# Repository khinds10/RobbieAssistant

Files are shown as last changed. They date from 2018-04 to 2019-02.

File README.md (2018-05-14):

# RobbieAssistant
Desktop Phone Notification Assistant Featuring (R.O.B.) Robotic Operating Buddy

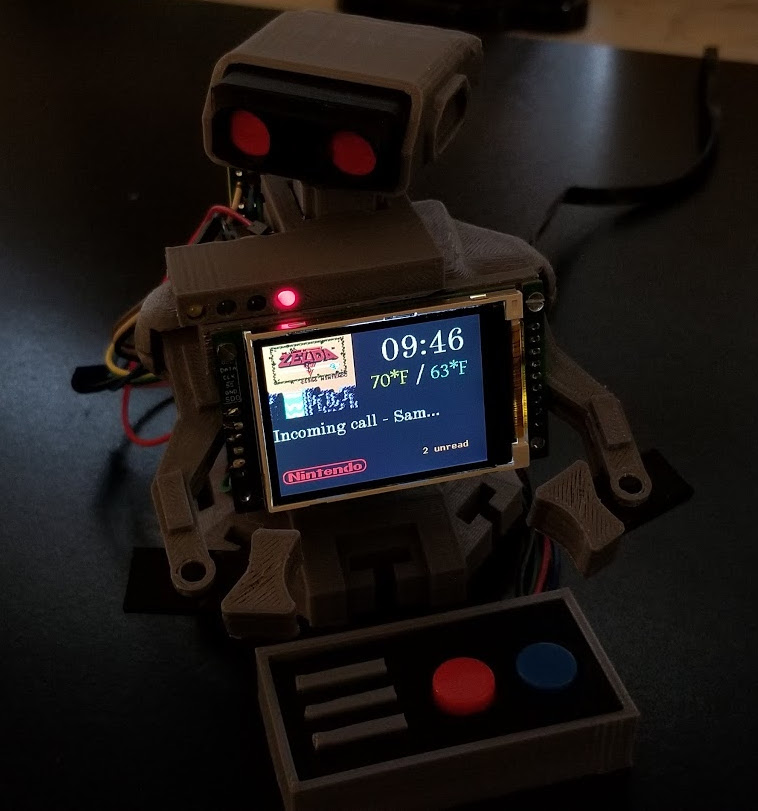
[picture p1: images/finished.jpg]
Finished!


Demo

#### Flashing RaspberriPi Hard Disk / Install Required Software (Using Ubuntu Linux)

Download "RASPBIAN JESSIE LITE"
https://www.raspberrypi.org/downloads/raspbian/

**Create your new hard disk for DashboardPI**
>Insert the microSD to your computer via USB adapter and create the disk image using the `dd` command
>
> Locate your inserted microSD card via the `df -h` command, unmount it and create the disk image with the disk copy `dd` command
> 
> $ `df -h`
> */dev/sdb1       7.4G   32K  7.4G   1% /media/XXX/1234-5678*
> 
> $ `umount /dev/sdb1`
> 
> **Caution: be sure the command is completely accurate, you can damage other disks with this command**
> 
> *if=location of RASPBIAN JESSIE LITE image file*
> *of=location of your microSD card*
> 
> $ `sudo dd bs=4M if=/path/to/raspbian-jessie-lite.img of=/dev/sdb`
> *(note: in this case, it's /dev/sdb, /dev/sdb1 was an existing factory partition on the microSD)*

**Setting up your RaspberriPi**

*Insert your new microSD card to the raspberrypi and power it on with a monitor connected to the HDMI port*

Login
> user: **pi**
> pass: **raspberry**

Change your account password for security
>`sudo passwd pi`

Enable RaspberriPi Advanced Options
>`sudo raspi-config`

Choose:
`1 Expand File System`

`9 Advanced Options`
>`A2 Hostname`
>*change it to "RobbieAssistant"*
>
>`A4 SSH`
>*Enable SSH Server*
>
>`A7 I2C`
>*Enable i2c interface*

**Enable the English/US Keyboard**

>`sudo nano /etc/default/keyboard`

> Change the following line:
>`XKBLAYOUT="us"`

**Reboot PI for Keyboard layout changes / file system resizing to take effect**
>$ `sudo shutdown -r now`

**Auto-Connect to your WiFi**

>`sudo nano /etc/wpa_supplicant/wpa_supplicant.conf`

Add the following lines to have your raspberrypi automatically connect to your home WiFi
*(if your wireless network is named "linksys" for example, in the following example)*

	network={
	   ssid="linksys"
	   psk="WIRELESS PASSWORD HERE"
	}

**Reboot PI to connect to WiFi network**

>$ `sudo shutdown -r now`
>
>Now that your PI is finally on the local network, you can login remotely to it via SSH.
>But first you need to get the IP address it currently has.
>
>$ `ifconfig`
>*Look for "inet addr: 192.168.XXX.XXX" in the following command's output for your PI's IP Address*

**Go to another machine and login to your raspberrypi via ssh**

> $ `ssh pi@192.168.XXX.XXX`

**Start Installing required packages**

>$ `sudo apt-get update`
>
>$ `sudo apt-get upgrade`
>
>$ `sudo apt-get install build-essential tk-dev libbz2-dev libexpat1-dev liblzma-dev zlib1g-dev libdb5.3-dev libgdbm-dev libsqlite3-dev libssl-dev libncurses5-dev libncursesw5-dev libreadline6-dev python3-pip python3-requests python3-setuptools python3-urllib python3-urllib3 python3-requests vim git python-smbus i2c-tools python-imaging python-smbus build-essential python-dev rpi.gpio python3 python3-pip vim git python-smbus i2c-tools python-imaging python-smbus build-essential python-dev rpi.gpio python3 python3-pip libi2c-dev vim git python-smbus i2c-tools python-imaging python-smbus build-essential python-dev rpi.gpio python3 python3-pip python-gpiozero python-psutil xz-utils`
>
>$ `sudo pip install requests`

**Update local timezone settings

>$ `sudo dpkg-reconfigure tzdata`

`select your timezone using the interface`

**Setup the simple directory `l` command [optional]**

>`vi ~/.bashrc`
>
>*add the following line:*
>
>`alias l='ls -lh'`
>
>`source ~/.bashrc`

**Fix VIM default syntax highlighting [optional]**

>`sudo vi  /etc/vim/vimrc`
>
>uncomment the following line:
>
>_syntax on_

**make the logs folder for the application to run**

`mkdir /home/pi/RobbieAssistant/logs`

`chmod 777 /home/pi/RobbieAssistant/logs`

**Configure Application to run correctly in settings.py config file**

Find the file `settings-shadow.py` in the `/includes/` folder of the project and copy it to `settings.py` and adjust to your current settings

> \# forecast.io API key for local weather information
>
> weatherAPIURL = 'https://api.forecast.io/forecast/'
>
> weatherAPIKey = 'YOUR API KEY FOR FORECAST.IO'
> 
> \# optional for running the remote temp/humidity logger
>
> dashboardServer = 'mydevicelogger.com'
>
> \# search google to get the Latitude/Longitude for your home location
>
> latitude = 41.4552578
>
> longitude = -72.1665444
>

# Supplies Needed

**RaspberriPi Zero**

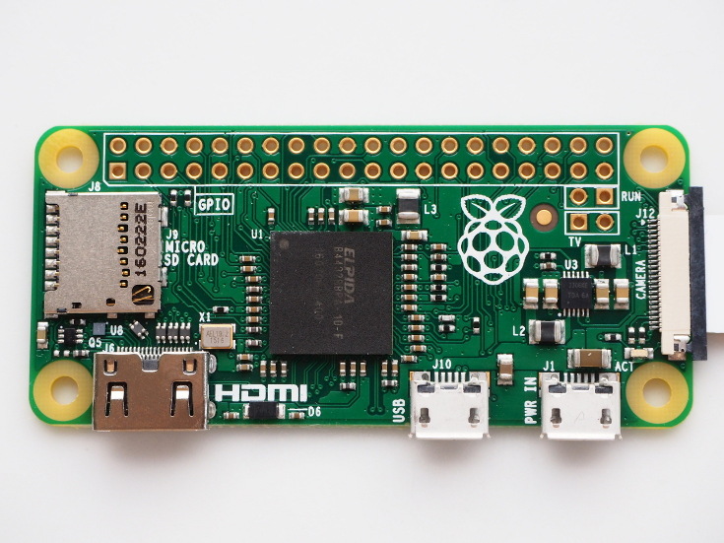
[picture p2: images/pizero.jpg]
Pi Zero


**DHT11 Humidistat**

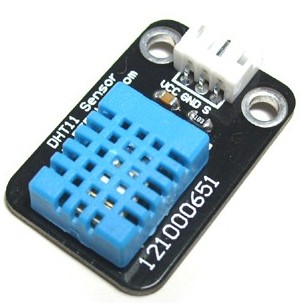
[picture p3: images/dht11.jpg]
DHT11 Humidistat


LED Lights (x4) Green / Yellow / Blue / Red

LED Lights

**2.6" Digole Display**

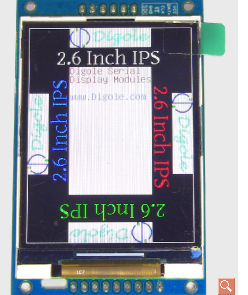
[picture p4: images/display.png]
Digole Display


## Build and wire the device

**1) Prepare the Digole Display for i2C**

On the back of the Digole Display, solder the jumper to assign the display to use the i2c protocol
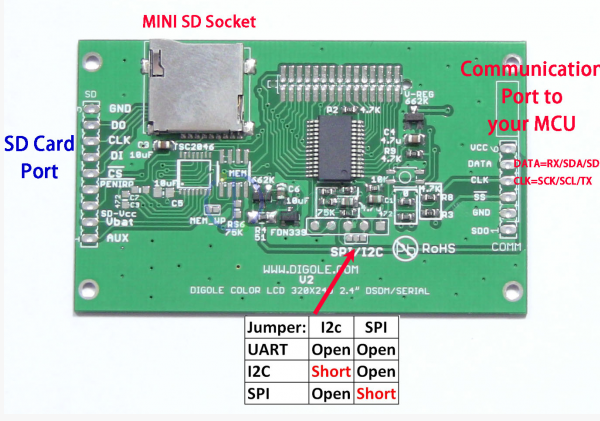
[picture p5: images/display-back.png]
i2c Jumper Digole


## Using a 3d printer, print the cover, box and back panels

Using the following X STL files in the `3DPrint` folder, R.O.B. Robot, LED Harness and Display Mount
>
> buttonContainer-base.stl
>
> buttonContainer-lid.stl
>
> displaymount-final.stl
>
> led-harness-final.stl
>
> MiniNintendoROB.zip

Robot Print by: Mini Nintendo R.O.B. - by RabbitEngineering

https://www.thingiverse.com/thing:1494964

I used red tape to make the eyes red with the black visor background

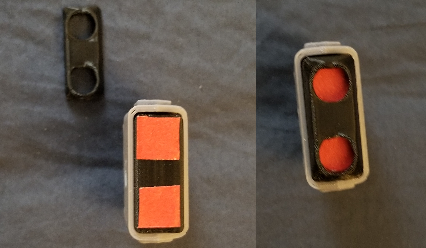
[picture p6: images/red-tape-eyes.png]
Red Tape


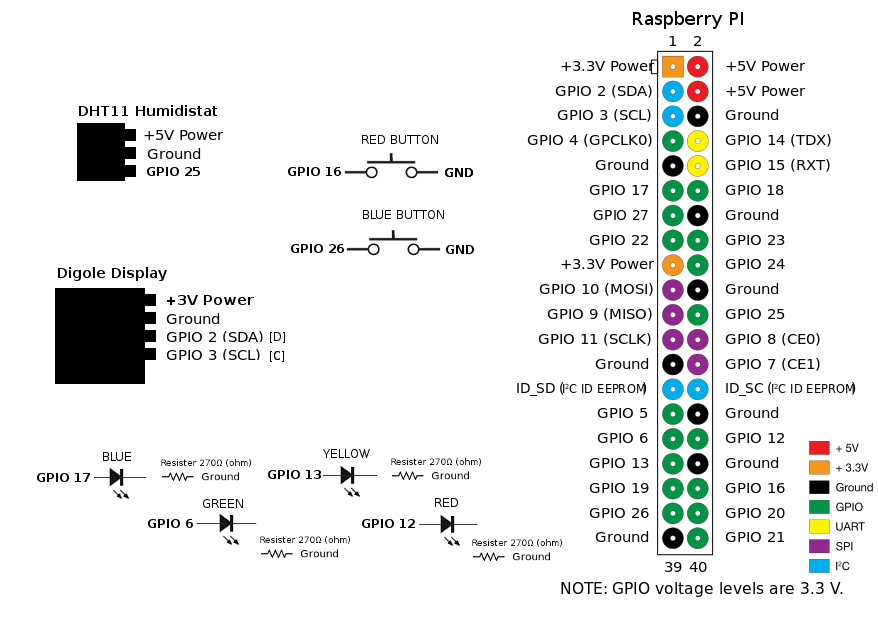
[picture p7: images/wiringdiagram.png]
Wiring Diagram


**Digole Display**
>
> GND -> GND
>
> DATA -> SDA
>
> CLK -> SCL
>
> VCC -> 3V
    
**DHT11 Humidistat**
>
> VCC -> 5V
>
> GND -> GND
>
> DATA -> GPIO 25
>

**BLUE Resistor**
>
> VCC -> GPIO 17 (with 270ohm resistor)
>
> GND -> GND
>

**YELLOW Resistor**
>
> VCC -> GPIO 13 (with 270ohm resistor)
>
> GND -> GND
>

**GREEN Resistor**
>
> VCC -> GPIO 6 (with 270ohm resistor)
>
> GND -> GND
>

**RED Resistor**
>
> VCC -> GPIO 12 (with 270ohm resistor)
>
> GND -> GND
>

**RED Momentary Pushbutton**
>
> VCC -> GPIO 16 (with 270ohm resistor)
>
> GND -> GND
>

**BLUE Momentary Pushbutton**
>
> VCC -> GPIO 26 (with 270ohm resistor)
>
> GND -> GND
>

After you've printed the screen holder, connect it to the digole display

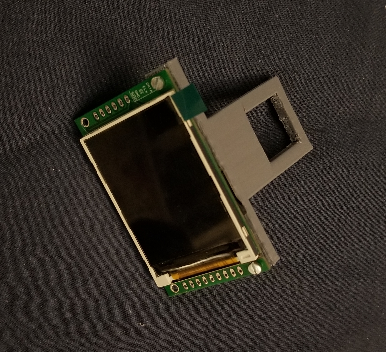
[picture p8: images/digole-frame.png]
Digole w/ Frame


Connect the Display to the RPi with enough wiring to glue the RPi to the back of the robot

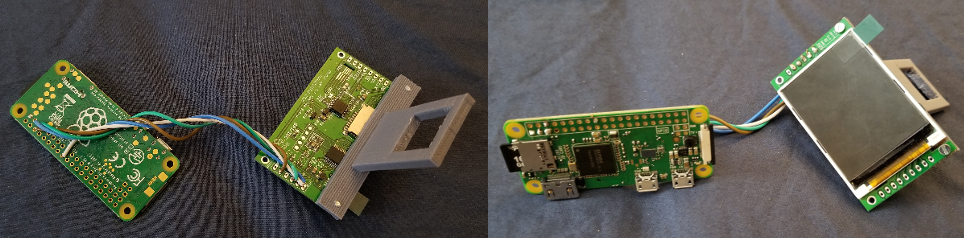
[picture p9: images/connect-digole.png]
Connect Digole


Print the controller and wire the buttons with enough wiring to make it to the back of the robot

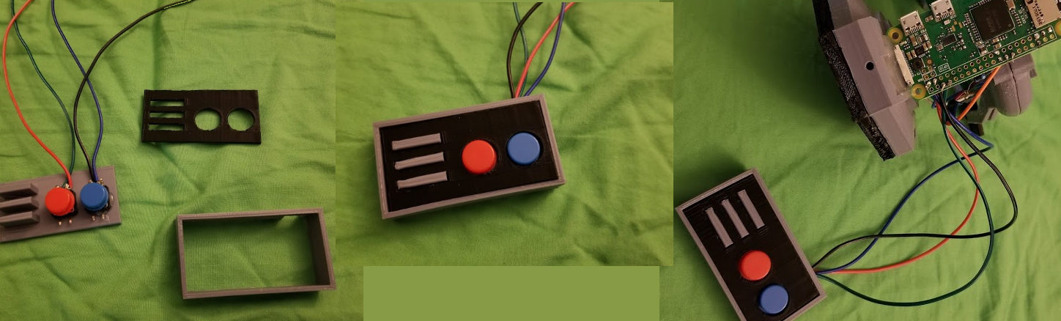
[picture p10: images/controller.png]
Controller


Finish Wiring and assembling the robot with the RPi connected to the back and the DHT11 glued to the bottom

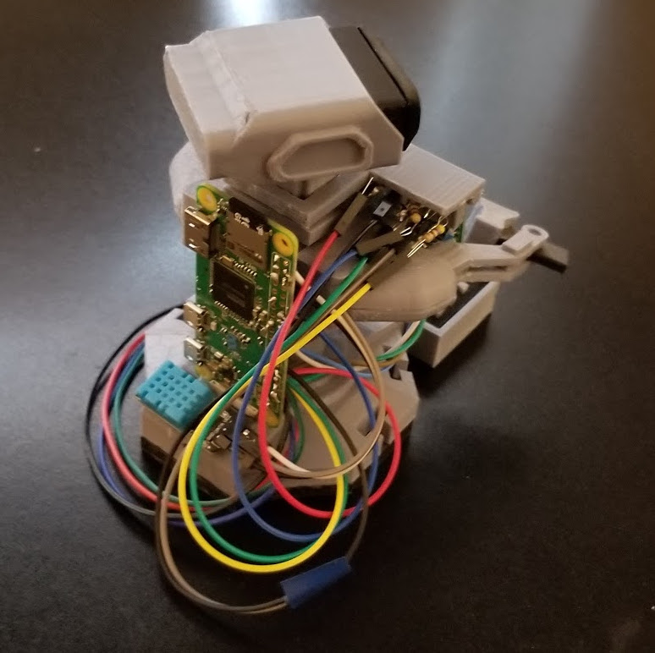
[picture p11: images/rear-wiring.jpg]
Rear Wiring


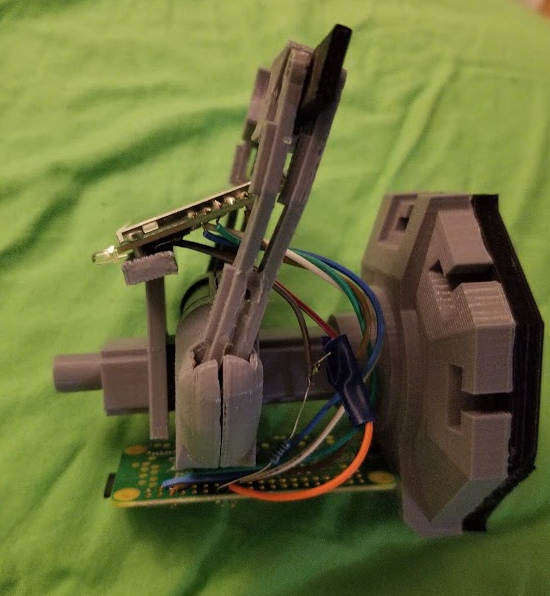
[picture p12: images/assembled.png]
Assembled


## Check I2C Configuration

Start up your RaspberryPi and make sure the I2C bus recognizes all your connected 7/14 segment displays. 
*[each display is given a unique address described above by how you solder each display's jumpers in different combinations]*

If you have the display with jumper soldered correctly, you should have the following output for the `i2cdetect` command:

`sudo i2cdetect -y 1`
     
>     0  1  2  3  4  5  6  7  8  9  a  b  c  d  e  f
>
>00:          -- -- -- -- -- -- -- -- -- -- -- -- -- 
>
>10: -- -- -- -- -- -- -- -- -- -- -- -- -- -- -- -- 
>
>20: -- -- -- -- -- -- -- 27 -- -- -- -- -- -- -- -- 
>
>30: -- -- -- -- -- -- -- -- -- -- -- -- -- -- -- -- 
>
>40: -- -- -- -- -- -- -- -- -- -- -- -- -- -- -- -- 
>
>50: -- -- -- -- -- -- -- -- -- -- -- -- -- -- -- -- 
>
>60: -- -- -- -- -- -- -- -- -- -- -- -- -- -- -- -- 
>
>70: -- -- -- -- -- -- -- --
>

**DHT11 Install**

>$ `cd ~`
>
>$ `git clone https://github.com/adafruit/Adafruit_Python_DHT.git`
>
>$ `cd Adafruit_Python_DHT/`
>
>$ `sudo python setup.py install`
>
>$ `sudo python ez_setup.py`
>
>$ `cd examples/`
>
>$ `vi simpletest.py`
>

Change the following line:
> sensor = Adafruit_DHT.DHT11

Comment the line out
> pin = 'P8_11'

Uncomment the line and change the pin number to 16
> pin = 25

Run the test

`python simpletest.py`

> You should see a metric reading of Temp and Humidity displayed on the command line.

**Clone RobbieAssistant repository**

>$ `cd ~`
>
>$ `git clone https://github.com/khinds10/RobbieAssistant.git`

**PushBullet/**

*Using the pushbullet app for your phone, signup to recieve an API key to have a simple python script be able to capture and push data hub notifications and indicator flags*

Install Python 3.5 for asyncio functionality

	sudo apt-get update
	sudo apt-get install build-essential tk-dev
	sudo apt-get install libncurses5-dev libncursesw5-dev libreadline6-dev
	sudo apt-get install libdb5.3-dev libgdbm-dev libsqlite3-dev libssl-dev
	sudo apt-get install libbz2-dev libexpat1-dev liblzma-dev zlib1g-dev

If one of the packages cannot be found, try a newer version number (e.g. libdb5.4-dev instead of libdb5.3-dev).

	wget https://www.python.org/ftp/python/3.5.2/Python-3.5.2.tgz
	tar zxvf Python-3.5.2.tgz
	cd Python-3.5.2
	./configure --prefix=/usr/local/opt/python-3.5.2
	make
	sudo make install
	sudo ln -s /usr/local/opt/python-3.5.2/bin/pydoc3.5 /usr/bin/pydoc3.5
	sudo ln -s /usr/local/opt/python-3.5.2/bin/python3.5 /usr/bin/python3.5
	sudo ln -s /usr/local/opt/python-3.5.2/bin/python3.5m /usr/bin/python3.5m
	sudo ln -s /usr/local/opt/python-3.5.2/bin/pyvenv-3.5 /usr/bin/pyvenv-3.5
	sudo ln -s /usr/local/opt/python-3.5.2/bin/pip3.5 /usr/bin/pip3.5
	cd ~
	echo 'alias python35="/usr/local/opt/python-3.5.2/bin/python3.5"' >> .bashrc
	echo 'alias idle35="/usr/local/opt/python-3.5.2/bin/python3.5"' >> .bashrc

Install the python3 dependancies

	sudo apt-get install python3-setuptools
	sudo apt-get install python3-pip
	sudo pip3 install asyncpushbullet
    sudo pip3 install requests
    
*Optional way* Download the python repository directly to obtain the python dependancies without the use of pip installing it

    git clone https://github.com/rharder/asyncpushbullet
    cd asyncpushbullet && sudo /usr/local/opt/python-3.5.2/bin/python3.5 setup.py install

Visit the pushbullet settings page in your account to generate an API key to use
https://www.pushbullet.com/#settings

Configure your `pushbullet-listener.py` script to have the correct API and dashboard central host

	# your API Key from PushBullet.com
	API_KEY = "o.XXXYYYZZZ111222333444555666"

	# dashboard central server host
	dashboardServer = 'MY-SERVER-HERE.com'

Add the script to start at dashboard boot and restart your dashboard pi

$ `crontab -e`

`@reboot nohup /usr/local/opt/python-3.5.2/bin/python3.5 /home/pi/PushBullet/pushbullet-listener.py >/dev/null 2>&1`

`@reboot nohup /usr/local/opt/python-3.5.3/bin/python3.5 /home/pi/RobbieAssistant/PushBullet/pushbullet-listener.py > /dev/null 2>&1`

`@reboot nohup python /home/pi/RobbieAssistant/Robbie.py > /dev/null 2>&1`

`@reboot nohup python /home/pi/RobbieAssistant/Temp.py > /dev/null 2>&1`

`@reboot nohup python /home/pi/RobbieAssistant/Weather.py > /dev/null 2>&1`

## OPTIONAL: Creating your own Nintendo images to render on the display

Upload your own 128x128 file to the following URL:

http://www.digole.com/tools/PicturetoC_Hex_converter.php 

Choose your image file to upload, add what size you want it to be on the screen (Width/Height)

Select "256 Color for Color OLED/LCD(1 byte/pixel)" in the "Used for" dropdown

Obtain the hex output.

Add the hex output to a display/build/ header (.h) file, use the other ones as guides for syntax.

Include the new file in the digole.c file 
`#include "myimage.h`

Include a new command line hook to your image file in the.
_Note: the command below is saying draw your image at position 10 pixels over 10  pixels down. You can change it to different X,Y coordinates, you can also change the values 128,128 to whatever size your new image actually is._

`} else if (strcmp(digoleCommand, "myimage") == 0) {`
    `drawBitmap256(10, 10, 128, 128, &myimageVariableHere,0);  // myimageVariableHere is defined in your (.h) file`
`}`

Now rebuild (ignore the errors) below to have your new image render with the following command.
>$ `./digole myimage`

**Re-Building [Included] Digole Display Driver for your optional changes**

>$ `cd display/build`

>$ `gcc digole.c`

>$ `mv a.out ../../digole`

>$ `chmod +x ../../digole`

## Finished

Finished!

Demo

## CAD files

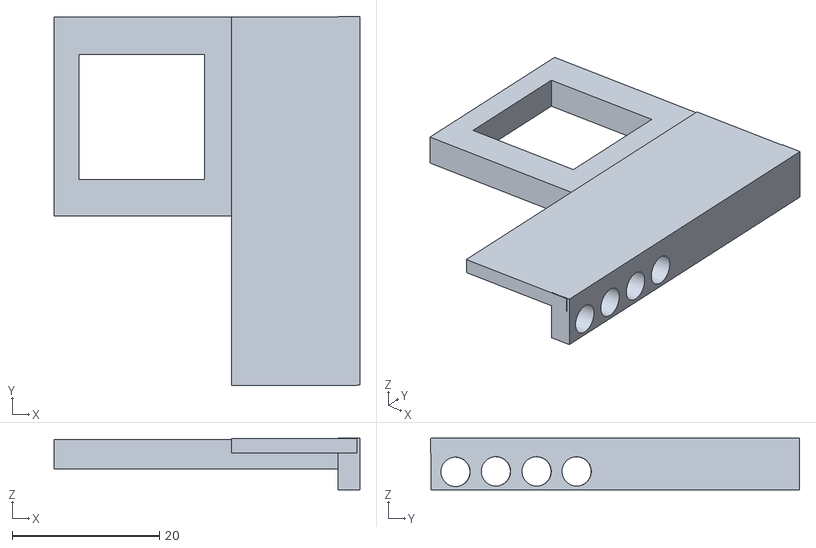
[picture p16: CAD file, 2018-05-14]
3DPrint/led-harness-final.stl
41.5 x 50.1 x 7.00

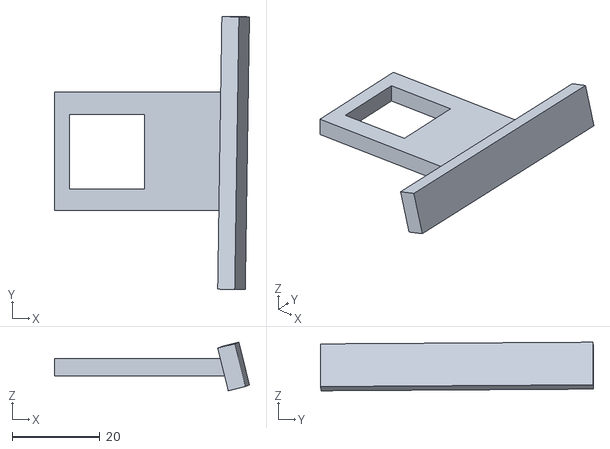
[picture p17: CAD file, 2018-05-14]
3DPrint/displaymount-final.stl
44.3 x 62.1 x 11.1

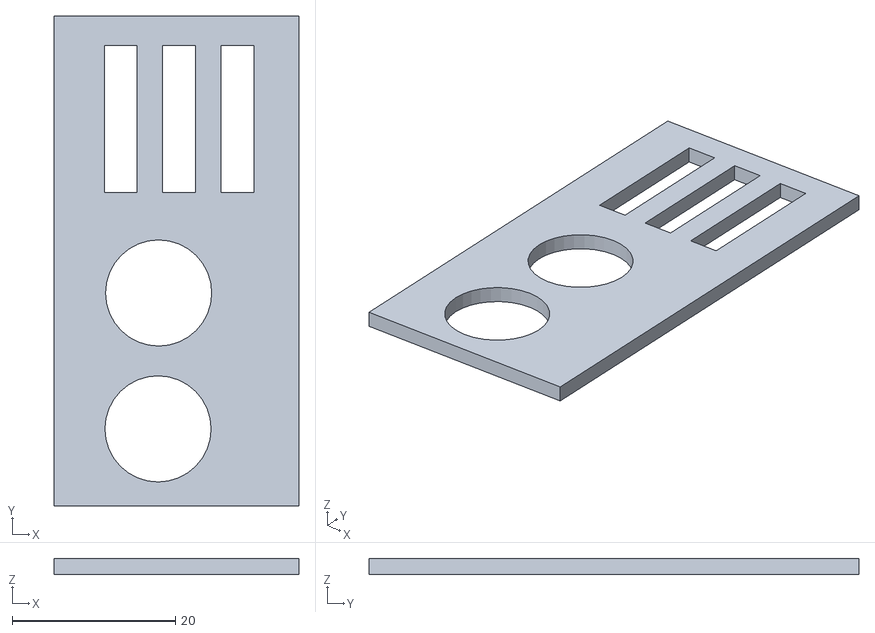
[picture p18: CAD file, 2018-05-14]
3DPrint/buttonContainer-lid.stl
30.0 x 60.0 x 2.00

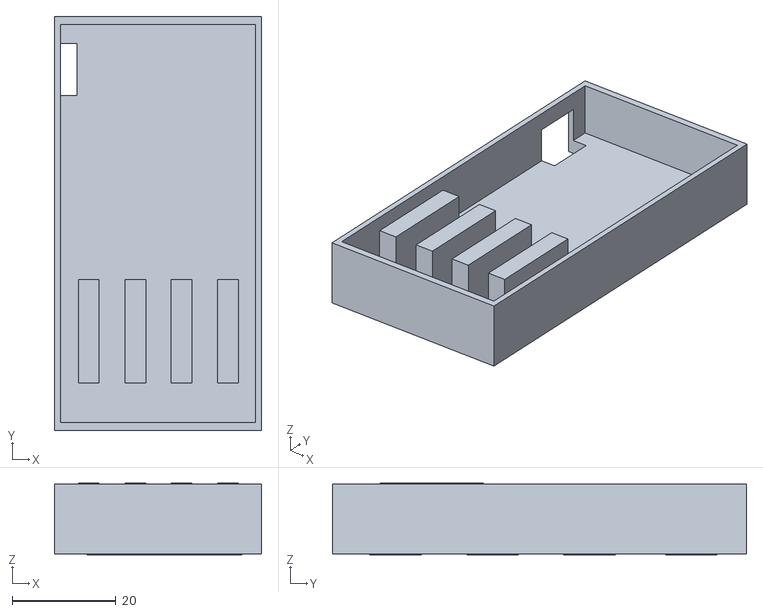
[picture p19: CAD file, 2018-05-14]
3DPrint/buttonContainer-base.stl
40.0 x 80.0 x 13.9

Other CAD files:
3DPrint/buttonContainer-base.blend
3DPrint/buttonContainer-lid.blend
3DPrint/displaymount-final.blend
3DPrint/led-harness-final.blend

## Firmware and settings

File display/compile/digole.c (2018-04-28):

/////////////////////////////////
// Digole Digital
/////////////////////////////////
#include <arpa/inet.h>
#include <dirent.h>
#include <errno.h>
#include <net/if.h>
#include <netinet/in.h>
#include <netinet/in.h>
#include <pthread.h>
#include <stdint.h>
#include <stdio.h>
#include <stdlib.h>
#include <string.h>
#include <stropts.h>
#include <sys/ioctl.h>
#include <sys/socket.h>
#include <sys/types.h>
#include <sys/time.h>
#include <time.h>
#include <unistd.h>
#include <inttypes.h>
#include <linux/i2c-dev.h>
#include <fcntl.h>
#include <sys/ioctl.h>
#include <sys/stat.h>

// include all the NES Title Screen Images
#include "BlasterMaster.h"
#include "Castlevania.h"
#include "ChipDale.h"
#include "Contra.h"
#include "ClearTitle.h"
#include "DuckTales.h"
#include "Galaga.h"
#include "GhostBusters.h"
#include "Gradius.h"
#include "KidIcarus.h"
#include "MarbleMadness.h"
#include "MegaMan.h"
#include "MetalGear.h"
#include "Metroid.h"
#include "PunchOut.h"
#include "SuperMario2.h"
#include "SuperMario3.h"
#include "TMNT2.h"
#include "TopGun.h"
#include "Turtles.h"
#include "Zelda.h"
#include "NES.h"

#define _TEXT_ 0
#define _GRAPH_ 1
#define _rs 0
#define _rst 2
#define LCDWIDTH 128
#define LCDHEIGHT 64

// an abs() :)
#define abs(a) (((a) < 0) ? -(a) : (a))

// bit set
#define _BV(bit) (0x1 << (bit))
#define swap(a, b) { uint8_t t = a; a = b; b = t; }

int fd,fd2;
const unsigned char fonts[] = {6, 10, 18, 51, 120, 123};

// name of the port we will be using, Rasberry Pi model B (i2c-1)
char *fileName = "/dev/i2c-1";

// address of I2C device Digole
int  address = 0x27;

void delay (unsigned int howLong){
  struct timespec sleeper, dummy ;
  sleeper.tv_sec  = (time_t)(howLong / 1000) ;
  sleeper.tv_nsec = (long)(howLong % 1000) * 1000000 ;
  nanosleep (&sleeper, &dummy) ;
}
 int writebyte (uint8_t command) {
	    if( i2c_smbus_write_byte( fd, command ) < 0 ) {
            printf(" Error writing to i2c slave ");
			return -1;
        }
		return 0;
 }
 int writecmd(char *command) {
		char tmp[1000];
		int i;
		sprintf(tmp,"%s",command);
        printf(" Digole CMD: %s ",command);
		for (i=0;i<strlen(tmp);i++) {
			printf("%c",tmp[i]);
		    if ((writebyte(tmp[i]))==-1) {
				printf(" Error writing to i2c slave ");
				return -1;
			}
		}
		return 0;
 }
void setRot90(void) {
    writecmd("SD1");
}
void setRot180(void) {
    writecmd("SD2");
}
void setRot270(void) {
    writecmd("SD3");
}
void undoRotation(void) {
    writecmd("SD0");
}
void setRotation(uint8_t d) {
    writecmd("SD");
    writebyte(d);
}
void setContrast(uint8_t c) {
    writecmd("CT");
    writebyte(c);
}
int print(char *command) {
    char tmp[1000];
    writecmd("TT");
    writecmd(command);
    writebyte(0);
    return 0;
}
void displayStartScreen(uint8_t c) {
    writecmd("DSS");
    writebyte(c);
}
void drawBox(uint8_t x, uint8_t y, uint8_t w, uint8_t h) {
    writecmd("FR");
    writebyte(x);
    writebyte(y);
    writebyte(x + w);
    writebyte(y + h);
}
void drawFrame(uint8_t x, uint8_t y, uint8_t w, uint8_t h) {
    writecmd("DR");
    writebyte(x);
    writebyte(y);
    writebyte(x + w);
    writebyte(y + h);
}
void setColor(uint8_t color) {
    writecmd("SC");
    writebyte(color);
}
void drawBoxfill(uint8_t x, uint8_t y, uint8_t w, uint8_t h) {
	setColor(0);
	drawBox(x, y, w,h);
	setColor(1);
	drawFrame(x, y, w,h);
}
void clearobd() {
	setColor(0);
	drawBox(0, 0, 128,57);
	setColor(1);
}
void drawCircle(uint8_t x, uint8_t y, uint8_t r, uint8_t f) {
    writecmd("CC");
    writebyte(x);
    writebyte(y);
    writebyte(r);
    writebyte(f);
}
void drawDisc(uint8_t x, uint8_t y, uint8_t r) {
    drawCircle(x, y, r, 1);
}
void drawPixel(uint8_t x, uint8_t y, uint8_t color) {
    writecmd("DP");
    writebyte(x);
    writebyte(y);
    writebyte(color);
}
void drawLine(uint8_t x, uint8_t y, uint8_t x1, uint8_t y1) {
    writecmd("LN");
    writebyte(x);
    writebyte(y);
    writebyte(x1);
    writebyte(y1);
}
void drawLineTo(uint8_t x, uint8_t y) {
    writecmd("LT");
    writebyte(x);
    writebyte(y);
}
void drawHLine(uint8_t x, uint8_t y, uint8_t w) {
    drawLine(x, y, x + w, y);
}
void drawVLine(uint8_t x, uint8_t y, uint8_t h) {
    drawLine(x, y, x, y + h);
}
void nextTextLine(void) {
    writebyte((uint8_t) 0);
    writecmd("TRT");
}
void setFont(uint8_t font) {
    writecmd("SF");
    writebyte(font);
}
void directCommand(uint8_t d) {
    writecmd("MCD");
    writebyte(d);
}
void directData(uint8_t d) {
    writecmd("MDT");
    writebyte(d);
}
void moveArea(uint8_t x0, uint8_t y0, uint8_t x1, uint8_t y1, char xoffset, char yoffset) {
    writecmd("MA");
    writebyte(x0);
    writebyte(y0);
    writebyte(x1);
    writebyte(y1);
    writebyte(xoffset);
    writebyte(yoffset);
}
void uploadStartScreen(int lon,  uint8_t *data,int xdelay) {
     int j,y;
     uint8_t c;
    writecmd("SSS");
    writebyte((uint8_t) (lon % 256));
    writebyte((uint8_t) (lon / 256));
    for (j = 0; j < lon;j++) {
        delay(xdelay);
        c=*(data+j);
        writebyte(c);
		printf(" 0x%.2X ",c);
		if ((j%16)==0) printf(" ");
    }
}
void uploadUserFont(int lon, uint8_t *data, uint8_t sect) {
     uint8_t c;
	 int j;
    writecmd("SUF");
    writebyte(sect);
    writebyte((uint8_t) (lon % 256));
    writebyte((uint8_t) (lon / 256));
    for ( j = 0; j < lon; j++) {
        if((j%32)==0) delay(10);
        delay(2);
        c=*(data+j);
        writebyte(c);
    }
}
void clearScreen(void) {
        writebyte('C');
		writebyte('L');
		writebyte(0);
		writebyte('C');
		writebyte('L');
		writebyte(0);
}
//set display mode
void setMode(uint8_t m) {
        writecmd("DM");
        writebyte(m);
}
//set text position back to previous, only one back allowed
void setTextPosBack(void) {
	writecmd("ETB");
}
void setTextPosOffset(char xoffset, char yoffset) {
	writecmd("ETO");
	writebyte(xoffset);
	writebyte(yoffset);
}
void setTextPosAbs(uint8_t x, uint8_t y) {
	writecmd("ETP");
	writebyte(x);
	writebyte(y);
}
void setLinePattern(uint8_t pattern) {
	writecmd("SLP");
	writebyte(pattern);
 }
void setPrintPos(uint8_t x, uint8_t y, uint8_t graph ) {
        if (graph == _TEXT_)
            writecmd("TP");
		else
            writecmd("GP");
         writebyte(x);
         writebyte(y);
}
void disableCursor(void) {
    writecmd("CS0");
}
void enableCursor(void) {
    writecmd("CS1");
}
void drawStr(uint8_t x, uint8_t y, char *s) {
		setTextPosOffset(x,y);
		print(s);
}
/*----------Functions for Graphic LCD/OLED adapters only---------*/
void drawBitmap(uint8_t x, uint8_t y, uint8_t w, uint8_t h, const uint8_t *bitmap) {
    uint8_t i = 0;
	int j;
    if ((w & 7) != 0)
        i = 1;
    writecmd("DIM");
    writebyte(x); //x;
    writebyte(y);
    writebyte(w);
    writebyte(h);
    for ( j = 0; j < h * ((w >> 3) + i); j++) {
        writebyte(*(bitmap + j));
    }
}
void drawBitmap256(uint8_t x, uint8_t y, uint8_t w, uint8_t h, unsigned char *bitmap,uint8_t c ) {
	int j;
    writecmd("EDIM1");
    writebyte(x);
    writebyte(y);
    writebyte(w);
    writebyte(h);    
    for ( j = 0; j < h * w; j++) {
        writebyte(*(bitmap + j));
    }
}
void drawBitmapc(uint8_t x, uint8_t y, uint8_t w, uint8_t h, unsigned char *bitmap,uint8_t c ) {
    uint8_t i = 0;
	int j;
	if (c!=0) c=0xff;
    if ((w & 7) != 0)
        i = 1;
    writecmd("EDIM1");
    writebyte(x);
    writebyte(y);
    writebyte(w);
    writebyte(h);
    for ( j = 0; j < h * ((w >> 3) + i); j++) {
        writebyte((*(bitmap + j))^c);
    }
}
const char *byte_to_binary(int x) {
    static char b[9];
    b[0] = '\0';
    int z;
    for (z = 128; z > 0; z >>= 1){
        strcat(b, ((x & z) == z) ? "1" : "0");
    }
    return b;
}
 int printxy(uint8_t x, uint8_t y, char *command) {
	setPrintPos(x, y,_TEXT_);
	writecmd("TT");
	writecmd(command);
	writebyte(0);
	return 0;
 }
 int printxy_abs(uint8_t x, uint8_t y, char *command) {
	setTextPosAbs(x, y);
	writecmd("TT");
	writecmd(command);
	writebyte(0);
	return 0;
 }
 int printxyf_abs(uint8_t x, uint8_t y,uint8_t font, char *command) {
	setFont(fonts[font]);
	setTextPosAbs(x, y);
	writecmd("TT");
	writecmd(command);
	writebyte(0);
	return 0;
 }
int printxyf(uint8_t x, uint8_t y,uint8_t font, char *command) {
	setFont(fonts[font]);
	setPrintPos(x, y,_TEXT_);
	writecmd("TT");
	writecmd(command);
	writebyte(0);
	return 0;
 }
int printnxyf(uint8_t x, uint8_t y,uint8_t font, int command) {
    char tmp[100];
    sprintf(tmp,"%d",command);
    setFont(fonts[font]);
    setPrintPos(x, y,_TEXT_);
    writecmd("TT");
    writecmd(tmp);
    writebyte(0);
    return 0;
 }
 int printnxyf_abs(uint8_t x, uint8_t y,uint8_t font, int command) {
    char tmp[100];
    sprintf(tmp,"%d",command);
    setFont(fonts[font]);
    setTextPosAbs(x, y);
    writecmd("TT");
    writecmd(tmp);
    writebyte(0);
    return 0;
 }
int LCDInit( uint8_t contrast) {
    // Open port for reading and writing
    if ((fd = open (fileName, O_RDWR)) < 0) {
        printf(" Failed to open i2c port ");
        return -1;
    }
    // Set the port options and set the address of the device
    if (ioctl(fd, I2C_SLAVE, address) < 0) {
        printf(" Unable to get bus access to talk to slave ");
        return -1;
    }
	return (0);
}
void LCDdrawbitmap(uint8_t x, uint8_t y, uint8_t *bitmap, uint8_t w, uint8_t h,uint8_t color,uint8_t *dest) {
uint8_t j,i,jj;
uint8_t o,p,k;
printf(" 000 0b ");
k=0;
for (p=0;p<(w/8);p++)
  for (o=0;o<=7;o++) {
		for ( j=0; j<h; j++) {
			for ( i=0; i<(w/8); i++ ) {
				uint8_t d = *(bitmap + i + (j)*w/8);
				for (jj = 8; jj>0; jj--)	{
					if (((jj-1)==(7-o)) && (i==p)) {
						if (d & _BV(jj-1))
						  printf("1");
						else
						  printf("0");
						k++;
						if (k%8==0)
							printf(",0b");
					 }
				}
			}
		}
		k=0;
		printf(" %.03d 0b ",(p*8)+o);
	}
}

int main (int argc, char* argv[]) {
    int i=0;
	LCDInit(0);
    printf(" %s ", argv[0]);

    // show incoming commands   
    printf(" arg%d=%s ", 1, argv[1]);
    printf(" arg%d=%s ", 2, argv[2]);

    // parse command to char
    char digoleCommand[100];
    sprintf(digoleCommand,"%s",argv[1]);
    
    // based on command issue call to Digole screen
    if (strcmp(digoleCommand, "setRot90") == 0) {
        setRot90();
    } else if (strcmp(digoleCommand, "setRot180") == 0) {
        setRot180();
    } else if (strcmp(digoleCommand, "setRot270") == 0) {
        setRot270();
    } else if (strcmp(digoleCommand, "undoRotation") == 0) {
        undoRotation();
    } else if (strcmp(digoleCommand, "setRotation") == 0) {
        setRotation((uint8_t)atoi(argv[2]));
    } else if (strcmp(digoleCommand, "setContrast") == 0) {
        setContrast((uint8_t)atoi(argv[2]));
    } else if (strcmp(digoleCommand, "displayStartScreen") == 0) {
        displayStartScreen((uint8_t)atoi(argv[2]));
    } else if (strcmp(digoleCommand, "drawBox") == 0) {
        drawBox((uint8_t)atoi(argv[2]), (uint8_t)atoi(argv[3]), (uint8_t)atoi(argv[4]), (uint8_t)atoi(argv[5]));
    } else if (strcmp(digoleCommand, "drawFrame") == 0) {
        drawFrame((uint8_t)atoi(argv[2]), (uint8_t)atoi(argv[3]), (uint8_t)atoi(argv[4]), (uint8_t)atoi(argv[5]));
    } else if (strcmp(digoleCommand, "setColor") == 0) {
        setColor((uint8_t)atoi(argv[2]));
    } else if (strcmp(digoleCommand, "drawBoxfill") == 0) {
        drawBoxfill((uint8_t)atoi(argv[2]), (uint8_t)atoi(argv[3]), (uint8_t)atoi(argv[4]), (uint8_t)atoi(argv[5]));
    } else if (strcmp(digoleCommand, "clearobd") == 0) {
        clearobd();
    } else if (strcmp(digoleCommand, "drawCircle") == 0) {
        drawCircle((uint8_t)atoi(argv[2]), (uint8_t)atoi(argv[3]), (uint8_t)atoi(argv[4]), (uint8_t)atoi(argv[5]));
    } else if (strcmp(digoleCommand, "drawDisc") == 0) {
        drawDisc((uint8_t)atoi(argv[2]), (uint8_t)atoi(argv[3]), (uint8_t)atoi(argv[4]));
    } else if (strcmp(digoleCommand, "drawPixel") == 0) {
        drawPixel((uint8_t)atoi(argv[2]), (uint8_t)atoi(argv[3]), (uint8_t)atoi(argv[4]));
    } else if (strcmp(digoleCommand, "drawLine") == 0) {
        drawLine((uint8_t)atoi(argv[2]), (uint8_t)atoi(argv[3]), (uint8_t)atoi(argv[4]), (uint8_t)atoi(argv[5]));
    } else if (strcmp(digoleCommand, "drawLineTo") == 0) {
        drawLineTo((uint8_t)atoi(argv[2]), (uint8_t)atoi(argv[3]));
    } else if (strcmp(digoleCommand, "drawHLine") == 0) {
        drawHLine((uint8_t)atoi(argv[2]), (uint8_t)atoi(argv[3]), (uint8_t)atoi(argv[4]));
    } else if (strcmp(digoleCommand, "drawVLine") == 0) {
        drawVLine((uint8_t)atoi(argv[2]), (uint8_t)atoi(argv[3]), (uint8_t)atoi(argv[4]));
    } else if (strcmp(digoleCommand, "nextTextLine") == 0) {
        nextTextLine();
    } else if (strcmp(digoleCommand, "setFont") == 0) {
        setFont((uint8_t)atoi(argv[2]));
    } else if (strcmp(digoleCommand, "directCommand") == 0) {
        directCommand((uint8_t)atoi(argv[2]));
    } else if (strcmp(digoleCommand, "directData") == 0) {
        directData((uint8_t)atoi(argv[2]));
    } else if (strcmp(digoleCommand, "moveArea") == 0) {
        moveArea((uint8_t)atoi(argv[2]), (uint8_t)atoi(argv[3]), (uint8_t)atoi(argv[4]), (uint8_t)atoi(argv[5]), (uint8_t)atoi(argv[6]), (uint8_t)atoi(argv[7]));
    } else if (strcmp(digoleCommand, "uploadStartScreen") == 0) {
        // uploadStartScreen(int lon,  uint8_t *data,int xdelay);
    } else if (strcmp(digoleCommand, "uploadUserFont") == 0) {
        // uploadUserFont(int lon, uint8_t *data, uint8_t sect);
    } else if (strcmp(digoleCommand, "clear") == 0) {
        clearScreen();
    } else if (strcmp(digoleCommand, "setMode") == 0) {
        setMode((uint8_t)atoi(argv[2]));
    } else if (strcmp(digoleCommand, "setTextPosBack") == 0) {
        setTextPosBack();
    } else if (strcmp(digoleCommand, "setTextPosOffset") == 0) {
        setTextPosOffset((uint8_t)atoi(argv[2]), (uint8_t)atoi(argv[3]));
    } else if (strcmp(digoleCommand, "setTextPosAbs") == 0) {
        setTextPosAbs((uint8_t)atoi(argv[2]), (uint8_t)atoi(argv[3]));
    } else if (strcmp(digoleCommand, "setLinePattern") == 0) {
        setLinePattern((uint8_t)atoi(argv[2]));
    } else if (strcmp(digoleCommand, "setPrintPos") == 0) {
        setPrintPos((uint8_t)atoi(argv[2]), (uint8_t)atoi(argv[3]), (uint8_t)atoi(argv[4]));
    } else if (strcmp(digoleCommand, "disableCursor") == 0) {
        disableCursor();
    } else if (strcmp(digoleCommand, "enableCursor") == 0) {
        enableCursor();
    } else if (strcmp(digoleCommand, "drawStr") == 0) {
        drawStr((uint8_t)atoi(argv[2]), (uint8_t)atoi(argv[3]), argv[4]);
    } else if (strcmp(digoleCommand, "drawBitmap") == 0) {
        // drawBitmap((uint8_t)atoi(argv[2]), (uint8_t)atoi(argv[3]), (uint8_t)atoi(argv[4]), (uint8_t)atoi(argv[5]), (uint8_t)atoi(argv[2]));
    } else if (strcmp(digoleCommand, "drawBitmap256") == 0) {
        // drawBitmapc((uint8_t)atoi(argv[2]), (uint8_t)atoi(argv[2]), (uint8_t)atoi(argv[2]), (uint8_t)atoi(argv[2]), const uint8_t *bitmap,uint8_t c );
    } else if (strcmp(digoleCommand, "print") == 0) {
        print(argv[2]);
    } else if (strcmp(digoleCommand, "printxy") == 0) {
        printxy((uint8_t)atoi(argv[2]), (uint8_t)atoi(argv[3]), argv[4]);
    } else if (strcmp(digoleCommand, "printxy_abs") == 0) {
        printxy_abs((uint8_t)atoi(argv[2]), (uint8_t)atoi(argv[3]), argv[4]);
    } else if (strcmp(digoleCommand, "printxyf_abs") == 0) {
        printxyf_abs((uint8_t)atoi(argv[2]), (uint8_t)atoi(argv[3]),(uint8_t)atoi(argv[4]), argv[5]) ;
    } else if (strcmp(digoleCommand, "printxyf") == 0) {
        printxyf((uint8_t)atoi(argv[2]), (uint8_t)atoi(argv[3]),(uint8_t)atoi(argv[4]), argv[5]);
    } else if (strcmp(digoleCommand, "printnxyf") == 0) {
        printnxyf((uint8_t)atoi(argv[2]), (uint8_t)atoi(argv[3]),(uint8_t)atoi(argv[4]), (uint8_t)atoi(argv[5]));
    } else if (strcmp(digoleCommand, "printnxyf_abs") == 0) {
        printnxyf_abs((uint8_t)atoi(argv[2]), (uint8_t)atoi(argv[3]),(uint8_t)atoi(argv[4]), (uint8_t)atoi(argv[5]));
    } else if (strcmp(digoleCommand, "LCDdrawbitmap") == 0) {
        //LCDdrawbitmap((uint8_t)atoi(argv[2]), (uint8_t)atoi(argv[3]), (uint8_t)atoi(argv[4]), (uint8_t)atoi(argv[5]), (uint8_t)atoi(argv[6]),(uint8_t)atoi(argv[7]),(uint8_t)argv[8]);
    } else if (strcmp(digoleCommand, "BlasterMaster") == 0) {
        drawBitmap256(0, 0, 128, 120, &BlasterMaster,0);
    } else if (strcmp(digoleCommand, "Castlevania") == 0) {
        drawBitmap256(0, 0, 128, 112, &Castlevania,0);
    } else if (strcmp(digoleCommand, "ChipDale") == 0) {
        drawBitmap256(0, 0, 128, 120, &ChipDale,0);
    } else if (strcmp(digoleCommand, "Contra") == 0) {
        drawBitmap256(0, 0, 128, 120, &Contra,0);
    } else if (strcmp(digoleCommand, "DuckTales") == 0) {
        drawBitmap256(0, 0, 128, 112, &DuckTales,0);
    } else if (strcmp(digoleCommand, "Galaga") == 0) {
        drawBitmap256(0, 0, 128, 112, &Galaga,0);
    } else if (strcmp(digoleCommand, "GhostBusters") == 0) {
        drawBitmap256(0, 0, 128, 122, &GhostBusters,0);
    } else if (strcmp(digoleCommand, "Gradius") == 0) {
        drawBitmap256(0, 0, 128, 120, &Gradius,0);
    } else if (strcmp(digoleCommand, "KidIcarus") == 0) {
        drawBitmap256(0, 0, 128, 112, &KidIcarus,0);
    } else if (strcmp(digoleCommand, "MarbleMadness") == 0) {
        drawBitmap256(0, 0, 128, 120, &MarbleMadness,0);
    } else if (strcmp(digoleCommand, "MegaMan") == 0) {
        drawBitmap256(0, 0, 128, 120, &MegaMan,0);
    } else if (strcmp(digoleCommand, "MetalGear") == 0) {
        drawBitmap256(0, 0, 128, 120, &MetalGear,0);
    } else if (strcmp(digoleCommand, "Metroid") == 0) {
        drawBitmap256(0, 0, 128, 107, &Metroid,0);
    } else if (strcmp(digoleCommand, "PunchOut") == 0) {
        drawBitmap256(0, 0, 128, 112, &PunchOut,0);
    } else if (strcmp(digoleCommand, "SuperMario2") == 0) {
        drawBitmap256(0, 0, 128, 120, &SuperMario2,0);
    } else if (strcmp(digoleCommand, "SuperMario3") == 0) {
        drawBitmap256(0, 0, 128, 115, &SuperMario3,0);
    } else if (strcmp(digoleCommand, "TMNT2") == 0) {
        drawBitmap256(0, 0, 128, 112, &TMNT2,0);
    } else if (strcmp(digoleCommand, "TopGun") == 0) {
        drawBitmap256(0, 0, 128, 112, &TopGun,0);
    } else if (strcmp(digoleCommand, "Turtles") == 0) {
        drawBitmap256(0, 0, 128, 120, &Turtles,0);
    } else if (strcmp(digoleCommand, "Zelda") == 0) {
        drawBitmap256(0, 0, 128, 116, &Zelda,0);
    } else if (strcmp(digoleCommand, "NES") == 0) {
        drawBitmap256(5, 200, 128, 24, &NES,0);
    } else if (strcmp(digoleCommand, "ClearTitle") == 0) {
        drawBitmap256(0, 0, 128, 120, &ClearTitle,0);
    }
    printf("\n");
	return 0;
}

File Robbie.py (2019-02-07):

#! /usr/bin/python
# R.O.B. Desktop Notification Assistant
# Kevin Hinds http://www.kevinhinds.com
# License: GPL 2.0
import time, commands, subprocess, re, json, sys, os
from random import randint
from gpiozero import Button
from datetime import datetime
import RPi.GPIO as GPIO
import includes.settings as settings
import includes.data as data
GPIO.cleanup()
GPIO.setmode(GPIO.BCM)

# setup LEDs by GPIO pins / buttons and turn off the lights
BLUE = 17
YELLOW = 13
GREEN = 6
RED = 12
GPIO.setup(BLUE,GPIO.OUT)
GPIO.setup(YELLOW,GPIO.OUT)
GPIO.setup(GREEN,GPIO.OUT)
GPIO.setup(RED,GPIO.OUT)
redButton = Button(16)
blueButton = Button(26)

# digole local executable for display and log file location
digoleCommand = "/home/pi/RobbieAssistant/digole"
notificationsLogFile = "/home/pi/RobbieAssistant/logs/notifications.log"

# begin default display text and button listeners
subprocess.call([digoleCommand, "setRot90"])
subprocess.call([digoleCommand, "clear"])
subprocess.call([digoleCommand, "setColor", "255"])

def randomTitleScreen():
    '''show NES game title screen on the Digole Display
    @titleScreenNumber : number 1 to 20 of which title screen to show
    '''

    # clear the previous title screen
    isUpdatingTitle = True
    subprocess.call([digoleCommand, "ClearTitle"])
    subprocess.call([digoleCommand, "NES"])

    # show one of 20 titles
    titleScreenNumber = randint(1,20)
    if titleScreenNumber == 1:
        subprocess.call([digoleCommand, "BlasterMaster"])
    if titleScreenNumber == 2:
        subprocess.call([digoleCommand, "Castlevania"])
    if titleScreenNumber == 3:
        subprocess.call([digoleCommand, "ChipDale"])
    if titleScreenNumber == 4:
        subprocess.call([digoleCommand, "Contra"])
    if titleScreenNumber == 5:
        subprocess.call([digoleCommand, "DuckTales"])
    if titleScreenNumber == 6:
        subprocess.call([digoleCommand, "Galaga"])
    if titleScreenNumber == 7:
        subprocess.call([digoleCommand, "GhostBusters"])
    if titleScreenNumber == 8:
        subprocess.call([digoleCommand, "Gradius"])
    if titleScreenNumber == 9:
        subprocess.call([digoleCommand, "KidIcarus"])
    if titleScreenNumber == 10:
        subprocess.call([digoleCommand, "MarbleMadness"])
    if titleScreenNumber == 11:
        subprocess.call([digoleCommand, "MegaMan"])
    if titleScreenNumber == 12:
        subprocess.call([digoleCommand, "MetalGear"])
    if titleScreenNumber == 13:
        subprocess.call([digoleCommand, "Metroid"])
    if titleScreenNumber == 14:
        subprocess.call([digoleCommand, "PunchOut"])
    if titleScreenNumber == 15:
        subprocess.call([digoleCommand, "SuperMario2"])
    if titleScreenNumber == 16:
        subprocess.call([digoleCommand, "SuperMario3"])
    if titleScreenNumber == 17:
        subprocess.call([digoleCommand, "TMNT2"])
    if titleScreenNumber == 18:
        subprocess.call([digoleCommand, "TopGun"])
    if titleScreenNumber == 19:
        subprocess.call([digoleCommand, "Turtles"])
    if titleScreenNumber == 20:
        subprocess.call([digoleCommand, "Zelda"])
    isUpdatingTitle = False

def resetLights():
    '''THERE...ARE... FOUR LIGHTS!'''
    GPIO.output(BLUE,GPIO.LOW)
    GPIO.output(YELLOW,GPIO.LOW)
    GPIO.output(GREEN,GPIO.LOW)
    GPIO.output(RED,GPIO.LOW)

previousMessage = ''
def showMessage(message):
    '''show messages on screen, making the original message black first'''
    global previousMessage
    subprocess.call([digoleCommand, "setFont", "51"])
    subprocess.call([digoleCommand, "setColor", "0"])
    subprocess.call([digoleCommand, "printxy_abs", "0", "150", '                                                                                            '])
    subprocess.call([digoleCommand, "setColor", "255"])
    subprocess.call([digoleCommand, "printxy_abs", "0", "150", message])
    previousMessage = message
    
previousMessageCount = ''
def showUnreadMessageCount(count):
    '''show how many messages unread'''
    global previousMessageCount
    messageCount = str(count) + " unread"
    subprocess.call([digoleCommand, "setFont", "18"])
    subprocess.call([digoleCommand, "setColor", "0"])
    subprocess.call([digoleCommand, "printxy_abs", "220", "210", previousMessageCount])
    resetLights()
    if count > 0:
        subprocess.call([digoleCommand, "setColor", "250"])
        GPIO.output(RED,GPIO.HIGH)
    else:
        subprocess.call([digoleCommand, "setColor", "222"])
        GPIO.output(GREEN,GPIO.HIGH)
    subprocess.call([digoleCommand, "printxy_abs", "220", "210", messageCount])
    previousMessageCount = messageCount

def logMessageToFile(currentMessage):
    '''log messages to file for later reference'''
    file = open(notificationsLogFile,"a")
    file.write("\n" + currentMessage)

previousTime = ''
previousIndoorTemp = ''
previousOutdoorTemp = ''
def showTimeWeather():
    '''show time and weather'''
    global previousTime, previousIndoorTemp, previousOutdoorTemp
    
    # update time and weather
    now = datetime.now()
    tempInfo = data.getJSONFromDataFile('temp.data')
    weatherInfo = data.getJSONFromDataFile('weather.data')     
    
    if tempInfo != '' and weatherInfo != '':
        time = now.strftime("%I:%M")
        indoorTemp = data.convertToString(data.convertToInt(tempInfo['temp'])) + "*F"
        outdoorTemp = data.convertToString(data.convertToInt(weatherInfo['apparentTemperature'])) + "*F"
        
        subprocess.call([digoleCommand, "setFont", "123"])

        subprocess.call([digoleCommand, "setColor", "0"])
        subprocess.call([digoleCommand, "printxy_abs", "170", "50", previousTime])    
        subprocess.call([digoleCommand, "setColor", "255"])
        subprocess.call([digoleCommand, "printxy_abs", "170", "50", time])
        
        subprocess.call([digoleCommand, "setFont", "120"])

        subprocess.call([digoleCommand, "setColor", "0"])
        subprocess.call([digoleCommand, "printxy_abs", "150", "90", previousIndoorTemp])
        subprocess.call([digoleCommand, "setColor", "254"])
        subprocess.call([digoleCommand, "printxy_abs", "150", "90", indoorTemp])
        
        subprocess.call([digoleCommand, "setColor", "255"])
        subprocess.call([digoleCommand, "printxy_abs", "218", "90", "/"])
        
        subprocess.call([digoleCommand, "setColor", "0"])
        subprocess.call([digoleCommand, "printxy_abs", "240", "90", previousOutdoorTemp])
        subprocess.call([digoleCommand, "setColor", "223"])
        subprocess.call([digoleCommand, "printxy_abs", "240", "90", outdoorTemp])
        
        previousTime = time
        previousIndoorTemp = indoorTemp
        previousOutdoorTemp = outdoorTemp
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

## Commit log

2018-04-20 added digole display driver C files including the NES title screens
2018-04-28 added clear title to digole driver, finished robbie python script
2018-04-28 updated digole driver with clear title command
2018-05-06 added readme for instructions to build
    [buttonContainer-base.blend, buttonContainer-base.stl, buttonContainer-lid.blend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]
2018-05-14 fix clear message, fix clear title with different clear image
    [Robbie.py]
2019-02-07 try catch in case of network issues
    [Robbie.py]
